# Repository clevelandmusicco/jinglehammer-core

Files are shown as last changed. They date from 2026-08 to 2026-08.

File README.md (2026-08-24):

# Jinglehammer Core - Programmable MIDI Controller

The Jinglehammer Core is a 4 footswitch x 8 bank MIDI controller initially
designed for use with guitar effect pedals, but it can be used to control
anything that understands MIDI messages. Press a footswitch and it sends a
configurable bundle of Program Change and Control Change messages, with each
message free to target its own channel. Configuration lives in onboard flash
and survives power cycles; you edit it from a browser over USB, so there's no
separate app to install.

This repo holds the whole project: `software/` (RP2350 firmware plus the
browser-based config editor), `hardware/` (enclosure CAD and PCB design), and
`docs/` (design notes not tied to a single build artifact).

- Firmware is C + CMake with a VSCode workspace file provided
- Configuration webapp is simple HTML + Javascript with Python used for
  "building"
- PCB sources are in KiCad format and the Gerbers are tested at JLCPCB
- The enclosure source is provided in FreeCAD format, with STEP and 3MF files
  for use in your slicer of choice
  
> [!NOTE]
> Pictures of the hardware and the webapp coming soon.

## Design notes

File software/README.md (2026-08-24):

# Jinglehammer Core

A four-switch MIDI foot controller built on a Raspberry Pi Pico 2 (RP2350). Each
footswitch sends a configurable bundle of Program Change and Control Change
messages over hardware MIDI (UART) and USB-MIDI. Presets, banks, and channels
live in flash and are edited from a browser over USB-CDC. No drivers, no install.

Two pieces, each with its own README:

- [`firmware/`](firmware/README.md) - the C firmware and its Pico SDK build.
- [`webapp/`](webapp/README.md) - a single-file config editor that talks to the
  controller over WebSerial.

This directory is the whole software side. One level up, the repo also holds
`docs/` and `hardware/`, the latter for a 3D-printed enclosure and PCB design
files. Neither is part of any build here.

## Overall UX

The whole controller can effectively be taught in three sentences:

- Press 1–4 to select a preset in the active bank.
- Press the two left- or right-most switches simultaneously to move down or up a bank.
- Solid LEDs indicate Banks 1–4; blinking LEDs indicate Banks 5–8.

**Presets.** Also called "bundles". Selecting a preset sends that switch's message
bundle: Program Changes first, then Control Changes, each message on its own MIDI
channel.

Switches are momentary presets in "radio" mode. The switch you press becomes the
active one, its LED lights, the other three go dark.

**Banks.** Press SW1+SW2 together to step the active bank down, SW3+SW4 to step
it up. Two switches together is a "chord". A chord suppresses both switches'
presets, so changing bank spews no stray MIDI. After a step the LEDs show the
new bank for a little less than a second: banks 1-4 light LED 1-4 solid, banks
5-8 light the same four, but blinking.

Here's a visual of the LED feedback when navigating the banks:

```text
Bank 1 = ● ○ ○ ○
Bank 2 = ○ ● ○ ○
Bank 3 = ○ ○ ● ○
Bank 4 = ○ ○ ○ ●

Bank 5 = ◉ ○ ○ ○
Bank 6 = ○ ◉ ○ ○
Bank 7 = ○ ○ ◉ ○
Bank 8 = ○ ○ ○ ◉
```

where ◉ means blinking.

After one of the above is displayed, all four LEDs slowly pulse for about 2s while the
controller waits for you to pick a preset on the new bank. Pick one and it fires
normally. Pick nothing and the bank navigation is abandoned; the controller returns
to where you started.

Bank changes are RAM-only. Nothing reaches flash until you Save from the web
app, so the bank the controller boots into is whichever one was last written.

## Hardware summary

Four momentary footswitches (normally open to GND, internal pull-ups), four
active-high PWM-driven LEDs, and UART0 TX at 31250 baud into a standard
UART-to-MIDI output stage. MIDI is output only. USB is native and enumerates as
a composite CDC + USB-MIDI device, so the same cable carries MIDI and the config
link.

Pins and counts are in [`firmware/board.h`](firmware/board.h). Full table in the
[firmware README](firmware/README.md).

## Getting started

```sh
git clone https://github.com/clevelandmusicco/jinglehammer-core
cd jinglehammer-core/software
cmake --build firmware/build     # after a one-time configure, see firmware/README.md
./webapp/build.py                # generates webapp/index.html
```

In VSCode, open `jinglehammer.code-workspace` rather than the `software/` folder.
It is a multi-root workspace over `software/`, `firmware/` and `webapp/`, and it
is what makes VSCode pick up each half's `.vscode/` directory: opening `software/`
as a plain folder means `firmware/.vscode/` is never read, so the Pico extension
config, IntelliSense and all the tasks are silently ignored.

Tasks are namespaced by half and independent of each other:

| task | does |
| --- | --- |
| `firmware: build` | incremental `cmake --build build` |
| `firmware: configure` | fresh CMake configure with the SDK and toolchain paths |
| `firmware: clean rebuild` | wipe `build/`, reconfigure, build |
| `firmware: size` | flash/RAM footprint of the ELF |
| `firmware: deploy` | build, then `picotool load -fx` over USB |
| `webapp: build` | inline `src/` into `index.html` |
| `webapp: check` | fail if `index.html` is stale |
| `webapp: test` | rebuild, then run the gjs self-test |
| `webapp: open` | rebuild and open `index.html` in a browser |
| `all: build` | both halves, in parallel |
| `all: verify` | firmware build plus webapp self-test |
| `all: deploy` | firmware build, load over USB, rebuild the editor |

`firmware: deploy` uses picotool's `-f`, which reboots a running board into
BOOTSEL on its own, so you do not need to hold the button. That relies on the
reset interface the firmware exposes (`firmware/usb_reset_iface.c`), so a board
running some older build has to be flashed the manual way once before the task
starts working. The Pico extension's own generated tasks (`Compile Project`,
`Flash`, the reset ones) are still there and still work.

## Work in progress

This is NOT a finished project. Expect a lot of change (improvements?) in the coming
weeks.

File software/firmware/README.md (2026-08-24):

# Jinglehammer Core Firmware

C firmware for the RP2350 (Pico 2). Targets Pico SDK 2.2.0 and board `pico2`.
For what the controller actually does, see the [software README](../README.md); for
the config editor, [`../webapp/`](../webapp/README.md).

## Hardware

Pins, counts, and the MIDI baud rate all live in [`board.h`](board.h).

| Function | GPIO | Notes |
| --- | --- | --- |
| Footswitch 1-4 | GP2, GP3, GP4, GP5 | Momentary, normally open to GND. Internal pull-ups, so a press reads 0. |
| LED 1-4 | GP6, GP7, GP8, GP9 | Active high, PWM-driven so brightness can be faded. LED N pairs with switch N. |
| MIDI out | GP0 (UART0 TX) | 31250 baud 8N1, into a standard UART-to-MIDI output stage (5-pin DIN or TRS-A). Output only. |

> [!WARNING]
> These pins currently don't match the PCB layout! That will be resolved very soon.

USB is native and enumerates as a composite CDC + USB-MIDI device, so the same
cable carries MIDI and the config link.

## Source layout

One responsibility per module:

| File | Responsibility |
| --- | --- |
| `board.h` | Pins, counts, MIDI UART baud. |
| `config.[ch]` | Persisted data model, CRC-32, flash load/save, serialize seams. |
| `midi.[ch]` | Builds PC/CC bytes, emits a preset bundle to UART + USB. |
| `io.[ch]` | Polled switch debounce and PWM LED output. |
| `controller.[ch]` | Radio policy and bank navigation: press edges to MIDI + LEDs. |
| `cdc_proto.[ch]` | Framed read/write/save command set on USB-CDC. Non-blocking. |
| `main.c` | Init plus the super-loop. |
| `usb_descriptors.c`, `tusb_config.h` | TinyUSB composite CDC + MIDI device. |

Dependency direction: `main` wires everything; `controller` uses `config`,
`midi`, `io`; `cdc_proto` uses `config`; `midi` and `config` use `board`; `io`
uses `board`. No cycles.

## Setting up the Pico toolchain

For a fresh Pico 2 with nothing installed yet, use VS Code — it sets up
everything in one step and needs no manual PATH wrangling.

1. Install [VS Code](https://code.visualstudio.com/) and the
   [Raspberry Pi Pico extension](https://marketplace.visualstudio.com/items?itemName=raspberry-pi.raspberry-pi-pico).
2. Open [`software/jinglehammer.code-workspace`](../jinglehammer.code-workspace)
   in VS Code (not a plain folder). It's a multi-root workspace with this
   folder as one of the roots, which is what the checked-in
   [`.vscode/`](.vscode) config and the extension's path resolution need — VS
   Code only reads a folder's `.vscode/` when that folder is itself a
   workspace-folder root. Opening `software/` or the repo root as a plain
   folder skips it, and the Build/Flash buttons end up pointed at a build
   directory that doesn't exist.
3. Run the extension's "Import Project" flow once (it detects the existing
   `CMakeLists.txt`). This downloads the SDK, ARM toolchain, CMake, Ninja,
   OpenOCD, and picotool into `~/.pico-sdk/` — nothing is installed system-wide.

That's it. The extension's Configure / Build / Flash buttons work from here on.

**Manual setup** (skip the extension, use the CLI below): put the same tools
under `~/.pico-sdk/` yourself — Pico SDK 2.2.0 at `~/.pico-sdk/sdk/2.2.0`, ARM
toolchain 14_2_Rel1 at `~/.pico-sdk/toolchain/14_2_Rel1`, plus CMake, Ninja, and
picotool (any recent version of these three is fine).

## Building and flashing

### First flash, out of the box

A brand new Pico 2 has no firmware with the custom reset interface, so its
*only* way in is BOOTSEL mode:

1. Hold the **BOOTSEL** button, plug in USB, then let go. The board mounts as
   a mass-storage drive named `RP2350`.
2. Build the firmware (from this directory):

   ```sh
   cmake -S . -B build -G Ninja \
     -DPICO_SDK_PATH=$HOME/.pico-sdk/sdk/2.2.0 \
     -DPICO_TOOLCHAIN_PATH=$HOME/.pico-sdk/toolchain/14_2_Rel1 \
     -DPICO_BOARD=pico2
   cmake --build build
   ```

   Output: `build/midi_ctrl.uf2`.
3. Copy `build/midi_ctrl.uf2` onto the `RP2350` drive. The board flashes
   itself and reboots into the new firmware.

It now comes up on factory defaults: bank 1, four presets, switch 1 sending a
PC on channel 1 plus three CCs on channels 2 and 3.

### Every flash after that

Once the board is running a build that includes `usb_reset_iface.c` (true
after the first flash above), you don't need BOOTSEL again — the board can
reset itself over the USB cable:

```sh
cmake --build build
picotool load -fx build/midi_ctrl.uf2
```

`-f` reboots the board into BOOTSEL and `-x` runs the new image immediately
after.

**SWD** (CMSIS-DAP probe, VS Code task `Flash`) works too, for when USB isn't
an option. But most folks find `picotool load -fx` to be simpler.

## Debugging

stdio is off on both USB and UART0 by default: USB belongs to TinyUSB (CDC +
MIDI) and UART0 is the MIDI port. To get `printf` out, route stdio to a spare
UART, add `pico_enable_stdio_uart(midi_ctrl 1)` to `CMakeLists.txt`, and call
`stdio_init_all()` in `main`.

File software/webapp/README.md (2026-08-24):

# Config editor

`index.html` is the editor for the controller's presets, banks, and channels.
It talks over USB-CDC using WebSerial, so it opens straight off disk with
nothing installed. See the [software README](../README.md) for the
controller itself and [`../firmware/`](../firmware/README.md) for the device
side.

## Building

`index.html` is generated from `src/` and is not checked in, so build it once
after cloning:

```sh
./build.py
```

That inlines the template, CSS, and JS modules into one self-contained file.
No npm and no bundler; it is plain Python 3 stdlib, so it runs the same on
Linux, macOS, and Windows. The app has to ship as a single file because
WebSerial works from `file://` but ES modules do not.

- `./build.py --check` exits 1 if `index.html` is stale.
- `./test.py` rebuilds, then self-tests the byte codec and page load. Needs
  `gjs` (Debian/Ubuntu: `apt install gjs`).

Both scripts resolve their own directory from the script path, so they run
from any working directory.

Edit `src/`. Anything written to `index.html` is lost on the next build.

## Source layout

```text
src/index.template.html   page skeleton plus <!-- include: ... --> lines
src/style.css
src/js/config-schema.js   field table mirroring config_t, plus decode/encode
src/js/crc32.js           CRC-32 matching the firmware's
src/js/model.js           in-RAM blob and edit folding
src/js/protocol.js        CDC frame codec
src/js/commands.js        HELLO / READ / WRITE / SAVE / FACTORY / TEST
src/js/monitor.js         raw-frame monitor, taps Link.send and Link._parse
src/js/paging.js          bank tabs, edit vs active bank
src/js/render.js          DOM building
src/js/status.js          status pill and banner
src/js/wiring.js          button listeners and startup
test/selftest.js          codec offsets and page-load test, run by test.py
```

`config-schema.js` mirrors the firmware's `config_t` name-for-name, and every
offset in the app derives from that one table. The constants in
`test/selftest.js` are hand-computed on purpose, so the schema cannot silently
agree with itself. A format change means editing both, plus `CONFIG_VER`.

## Editing presets

Open `index.html` in a Chromium-based browser (Chrome or Edge; Firefox and
Safari do not ship WebSerial). Plug the controller in over USB, then:

1. **Connect**, and pick the controller from the browser's port chooser.
2. **Read** to pull the current config off the device.
3. Edit each preset: name, plus its Program Change and Control Change
   lists (up to 16 of each, every message with its own 1-16 MIDI channel).
   **Test** plays a switch's bundle immediately from the on-screen values,
   without saving. Numbered tabs page through the 8 banks, and **Set as
   active** marks the bank the controller runs and boots on.
4. **Write + Save** sends all 8 banks and commits them to flash.

**Factory reset** overwrites the saved config with the built-in defaults.
**Frames** opens a raw-frame monitor for debugging the CDC link.

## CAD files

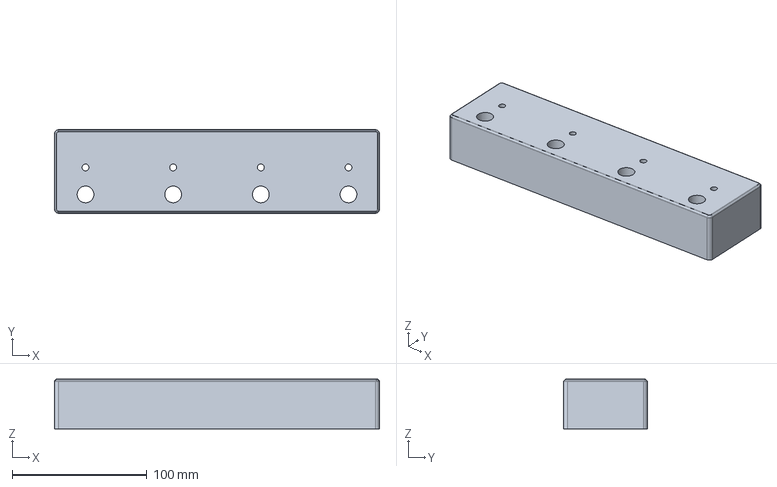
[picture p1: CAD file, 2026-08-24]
hardware/enclosure/enclosure-core.FCStd
241.0 x 62.0 x 37.0 mm

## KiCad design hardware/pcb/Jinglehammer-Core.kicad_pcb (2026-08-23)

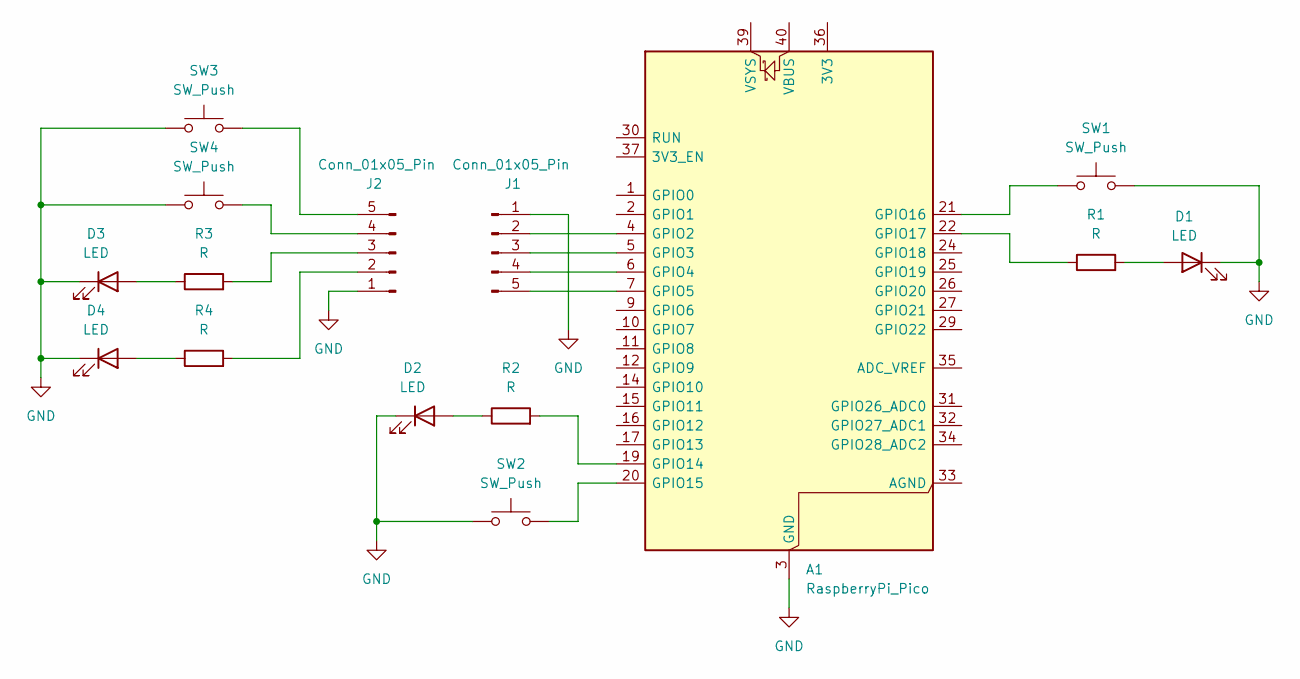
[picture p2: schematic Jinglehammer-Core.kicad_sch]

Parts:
A1: RaspberryPi_Pico; RaspberryPi_Pico_Common_Unspecified
D1, D2, D3, D4: LED; LED_D5.0mm
J1, J2: Conn_01x05_Pin; PinHeader_1x05_P2.54mm_Vertical
R1, R2, R3, R4: R; R_Axial_DIN0207_L6.3mm_D2.5mm_P7.62mm_Horizontal
SW1, SW2, SW3, SW4: SW_Push; Switch_Footswitch_PBS-24B-2_DirectMount

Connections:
GND: A1.3 (GND), A1.8 (GND), A1.13 (GND), A1.18 (GND), A1.23 (GND), A1.28 (GND), A1.38 (GND), D1.1 (K), D2.1 (K), D3.1 (K), D4.1 (K), J1.1, J2.1, SW1.1, SW2.1, SW3.1, SW4.1
unnamed: A1.4 (GPIO2), J1.2
unnamed: A1.5 (GPIO3), J1.3
unnamed: A1.6 (GPIO4), J1.4
unnamed: A1.7 (GPIO5), J1.5
unnamed: A1.19 (GPIO14), R2.2
unnamed: A1.20 (GPIO15), SW2.2
unnamed: A1.21 (GPIO16), SW1.2
unnamed: A1.22 (GPIO17), R1.1
unnamed: D1.2 (A), R1.2
unnamed: D2.2 (A), R2.1
unnamed: D3.2 (A), R3.1
unnamed: D4.2 (A), R4.1
unnamed: J2.2, R4.2
unnamed: J2.3, R3.2
unnamed: J2.4, SW4.2
unnamed: J2.5, SW3.2

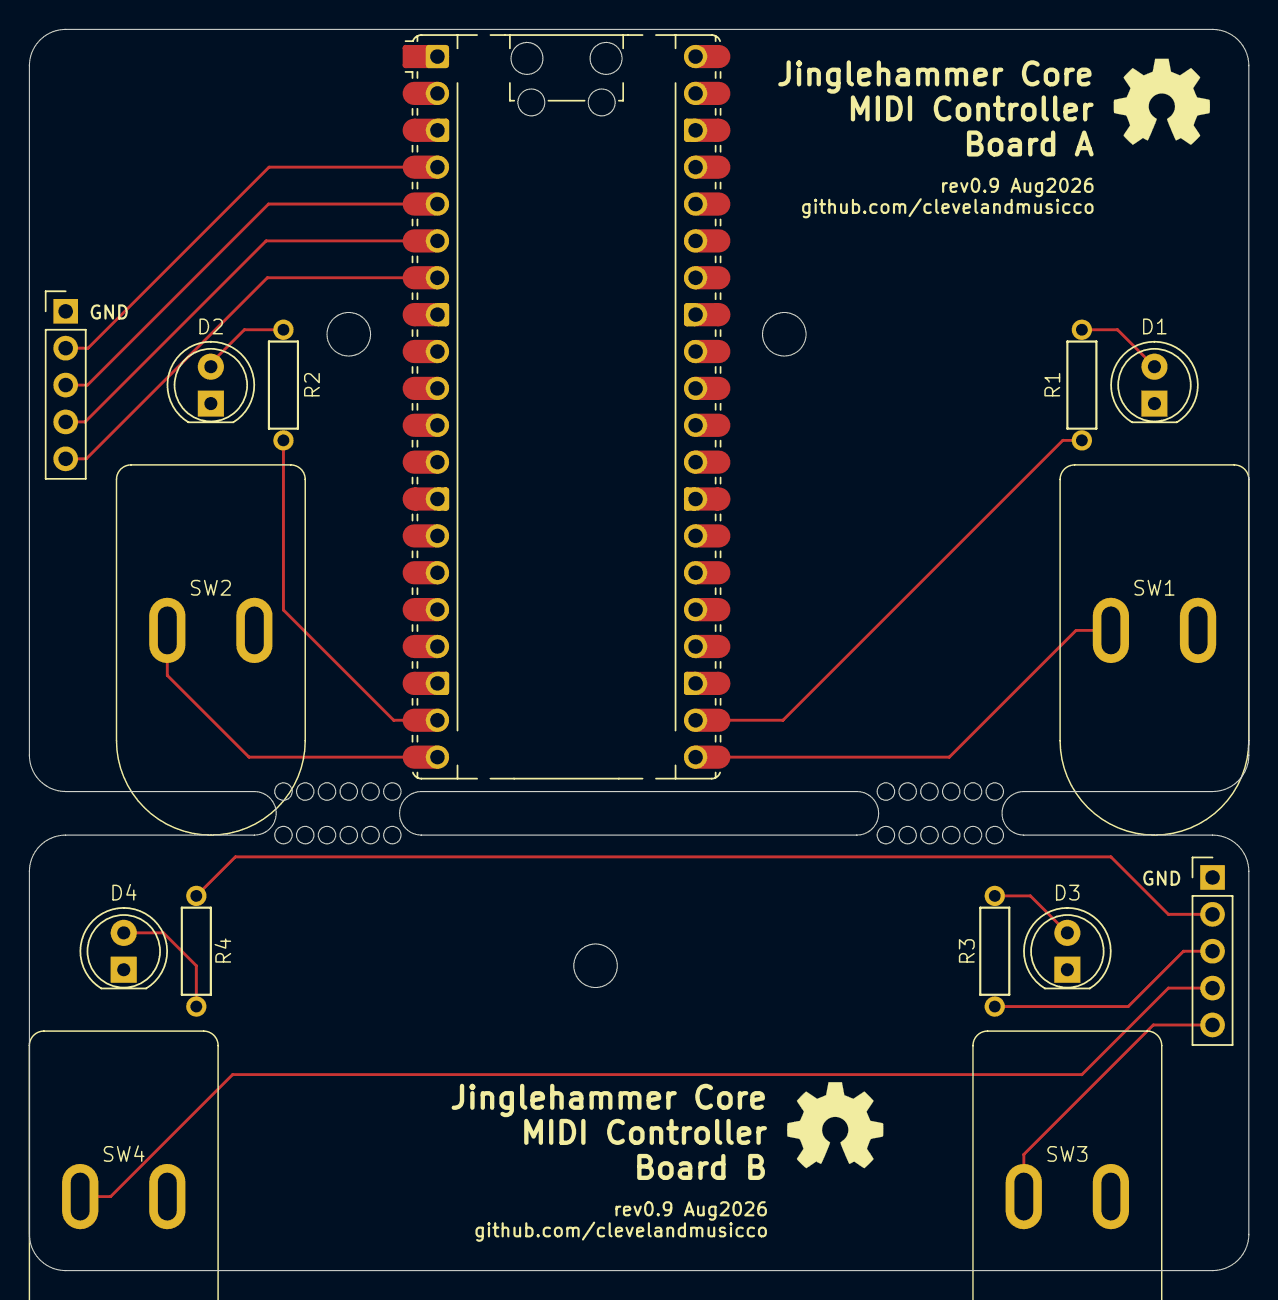
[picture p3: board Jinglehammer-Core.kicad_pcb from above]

Board: 2 copper layers, 84.0 x 85.5 mm, 15 parts (0 on the bottom side), 17 nets.

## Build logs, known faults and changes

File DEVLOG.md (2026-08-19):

# DEVLOG: bank-nav branch

Working log for the bank-navigation feature, branched off `main`. Purpose: let
future sessions (or future me) resume without re-deriving decisions already
made. Update this file each commit; keep it current, not historical - prune
resolved "open questions" rather than leaving them stale.

## Goal

Add bank up/down navigation on the footswitches, plus a temporary LED readout
of which bank is now active. Scope for this branch is mechanics + indicator
only; no webapp changes, no new switch modes beyond what's needed for this.

First cut used double-tap on SW1/SW4. Superseded (see below) by a two-switch
chord: double-tap fired each tap's own preset in addition to stepping the
bank, so a bank change always came with an unwanted MIDI fire from whichever
preset lived on that switch.

## Status

- `21667e1` - double-tap detection + bank step (`controller.c`) - **superseded**
- `4c79de1` - LED bank-display on top of that (`controller.c`, `controller.h`, `main.c`) - display logic carried forward as-is
- `71eb2a9` - replaced double-tap with a chord gesture; see Behaviour below.
- Current (uncommitted) - preset-wait after bank-display timeout, replacing
  the old "LED 0 = preset 1" placeholder; see Preset-wait section below.
- Not yet done: flashed/tested on real hardware. Everything below is
  desk-reviewed and builds clean, not yet felt with a boot.

## Behaviour, as built

- SW1+SW2 pressed together -> `active_bank -= 1`; SW3+SW4 together ->
  `active_bank += 1`. Clamped at 0 / `NUM_BANKS-1` (no wrap).
- A recognised chord suppresses both switches' normal preset fire entirely -
  only the bank step and LED display happen. This is the whole point of the
  switch from double-tap: no more MIDI collision between "I meant to change
  bank" and "that switch also has a preset."
- Chord partner pairing is `i ^ 1`: switches (0,1) are the down pair, (2,3)
  the up pair.
- Detection uses a tolerance window, not exact same-tick simultaneity. Each
  switch debounces independently (8ms shift register, see `io.c`), all four
  sampled in the same `io_poll()` call - but two real footswitch presses
  aimed at "the same moment" can still complete a poll tick or two apart. So
  every edge on SW1-4 is held pending for `CHORD_WINDOW_MS` (20ms: 8ms
  debounce + slack for press skew): if the partner edge shows up before the
  deadline (same tick or a later one), it's a chord - bank step fires,
  neither preset does, and the first-arriving switch's pending entry is
  cancelled without ever firing. If the deadline passes with no partner, it
  was a solo press - the queued preset fires then, late by at most
  `CHORD_WINDOW_MS`.
  - Consequence: **every** press on SW1-4 now carries up to 20ms of added
    latency, even a plain single-switch press, since the firmware can't know
    in advance whether a chord partner is coming. This is a deliberate
    tradeoff (user's call, see chat history) - 20ms is inaudible/imperceptible
    for PC/CC messages, traded for chords being reliably hittable by foot
    instead of requiring exact-tick luck.
- `active_bank` change is RAM-only - no `config_save()` call. Cheap to spam,
  survives until a webapp Save or reverts to the last-Saved bank on reboot.
- On a recognised chord (even one that clamps to the same bank - that's the
  "you're already at the end" feedback), LEDs switch to bank-display mode for
  800ms: LED `(bank % NUM_SWITCHES)` lights, solid for banks 1-4, blinking for
  banks 5-8. Unchanged from the double-tap version.
- Blink = 4 on/off cycles at 100ms/state, fills the 800ms window exactly.
- A later chord while the display is showing restarts the window/blink
  against the new bank.
- Any normal switch press (chord or solo-fire-after-timeout) preempts the
  display immediately and shows that press's radio LED instead - a fired
  preset always wins over a stale bank indicator.
- On bank-display timeout, the unit does **not** default to preset 1 - see
  "preset-wait" below, added after this was flagged as misleading (stepping a
  bank shouldn't silently imply picking a preset on it).

## Preset-wait (uncommitted, on top of the above)

Resolves the open question below about what happens after the bank-display
window: previously LED 0 lit as a "preset 1 of the new bank" placeholder with
no MIDI sent, which read as if a preset had actually been selected. Now:

- When `BANK_DISPLAY_WINDOW_MS` elapses, the unit enters a new LED mode
  (`LED_MODE_AWAIT_PRESET`) instead of returning straight to radio mode: all 4
  LEDs breathe together for `PRESET_WAIT_WINDOW_MS` (2000ms) - fade low-\>high
  over `PRESET_WAIT_STATE_MS` (500ms), then high-\>low over the next 500ms,
  repeat - 2 up/down cycles fill the window exactly, same "N units fill the
  window" pattern as the bank blink, just continuous brightness instead of a
  hard on/off toggle.
- First cut used a hard on/off blink (250ms/state, 4 cycles), same mechanism
  as bank-display's blink. Replaced with an actual fade after the ask for a
  smoother "breathing" look instead of a blink - see the `io.c` change below.
- Any normal press during the fade (chord or solo) preempts it immediately,
  same rule as bank-display preemption - the newly fired preset's radio LED
  wins and becomes the active preset going forward.
- Another chord during the fade restarts bank-display again against the
  further-stepped bank, then re-enters preset-wait - chaining chords keeps
  extending the sequence rather than committing anything.
- If the 2000ms window lapses with nothing picked, the whole navigation
  sequence is abandoned: `active_bank` reverts (RAM-only) to whatever it was
  *before the first chord in the sequence*. This is the literal "keep the old
  bank and preset" ask - a bank step is now provisional until a preset
  confirms it.
- First cut of the revert set the reverted-to preset's LED directly, with no
  indication a revert had even happened - visually indistinguishable from
  just picking that preset normally. Fixed per feedback: the revert now lands
  `active_bank` in RAM, then calls `start_bank_display(true)` to replay the
  *normal* bank-display readout (same position/blink code) for the bank
  being reverted to, and only after that window ends does it settle on the
  LED of the preset that was actually active before all this started (or off,
  pre-first-press). Worked example: bank 5 preset 3 active, SW3+4 steps to
  bank 6, nothing picked in time -> LED1 blinks (bank 5's display code),
  then LED3 lights solid (preset 3) - reads as "back to bank 5, preset 3,"
  not a silent snap.
- `start_bank_display()` takes an `is_revert` bool, stashed in
  `bank_display_revert`, so `controller_poll()` knows what to do once that
  display's own window ends: forward nav (`is_revert == false`) chains into
  `start_preset_wait()` as before; a revert (`is_revert == true`) settles
  straight into `LED_MODE_RADIO` showing `active_switch`. Same struct/timer/
  blink fields serve both cases - it's the same display, just two different
  reasons to be showing it and two different next steps.
- `controller_on_edges()` snapshots `g_config.active_bank` before its
  `bank_step()` call, but only commits it to `pre_nav_bank` (the revert
  target) when the sequence starts from `LED_MODE_RADIO` - a chord that lands
  mid-display or mid-wait (including during a revert's own display) must not
  overwrite the revert target with an intermediate bank. A fresh chord
  landing during a revert's display works out correctly anyway: by then
  `active_bank` has already been set to `pre_nav_bank` in RAM, so stepping
  from "current" and stepping from "the bank being reverted to" are the same
  number - the new chord just starts a normal forward nav from there,
  `bank_display_revert` gets reset to `false` for it, and `pre_nav_bank`
  isn't touched because `led_mode` isn't `LED_MODE_RADIO` at that instant.
- `controller_poll()` now does three jobs: fires any preset whose chord window
  expired with no partner, drives the bank-display deadline/blink, and drives
  the preset-wait deadline/fade (including the revert). All need to progress
  with no switch presses arriving, hence still polled every ~1ms from
  `main.c` independent of edges. The fade level is recomputed every poll tick
  (not just at the 500ms state boundary) by linearly interpolating elapsed
  time within the current ramp, so it reads as continuous motion rather than
  256 possible steps landing only every 500ms.
- `io.c` LEDs moved from plain `gpio_put` to hardware PWM
  (`gpio_set_function(..., GPIO_FUNC_PWM)`, 8-bit duty, `hardware_pwm` added
  to `target_link_libraries` in `CMakeLists.txt`) so brightness is controllable
  at all - `io_set_leds(mask)` keeps the old on/off call shape (duty 0 or 255),
  new `io_set_leds_level(level)` sets all 4 LEDs to the same 0-255 duty for the
  fade. LED1/LED2 (GP6/7) and LED3/LED4 (GP8/9) each share a PWM slice, but
  channels A/B have independent compare registers, so per-LED brightness
  still works independently - just don't call `pwm_init()` again after
  `io_init()`, since it resets both channels' compare registers on that slice.

## Known limits / assumptions

- Bank-display encoding (`position = bank % NUM_SWITCHES`, `blink = bank >=
  NUM_SWITCHES`) is only unambiguous up to `2 * NUM_SWITCHES` banks.
  `NUM_BANKS` is exactly that today (8 = 2*4). If `NUM_BANKS` ever grows past
  that, the display silently aliases - no guard exists for it, out of scope
  for this branch.
- Chord pairing (`i ^ 1`, delta by `i < 2`) is hardcoded for exactly 4
  switches split into two fixed pairs. Fine at `NUM_SWITCHES == 4`; would need
  rework if the switch count or pairing ever changes.
- Timing (chord window, display window, blink) is wall-clock (`absolute_time_t`
  / `time_reached`), not tied to poll count, so it degrades gracefully if
  `controller_poll()` call cadence ever drifts from 1ms - just coarser, not
  broken.
- No flash write ever happens from a chord. Same deliberate tradeoff as the
  double-tap version - flash write is blocking + wears the sector, bad fit for
  something tapped often mid-set.

## Open questions / next steps

- Hardware feel: `CHORD_WINDOW_MS` (20ms), 800ms display window, 100ms blink
  cadence - all reasonable guesses, untested on a real footswitch. The chord
  window in particular may need tuning: too short and intentional chords miss
  each other's tick, too long and fast sequential solo presses on SW1-4 risk
  being misread as a chord.
- Webapp is untouched. `active_bank` can now drift from what the webapp last
  saw without a Save - probably fine (Read already re-syncs), but no explicit
  decision was made about surfacing this in the UI.
- Fixed after the fact: nav state outlived the config it referred to. A web-app
  Write + Save (or factory reset) mid-nav got undone by the pending revert
  writing `pre_nav_bank` back over the bank the host had just installed - and a
  revert landing in the gap between WRITE and SAVE put the stale bank in flash.
  `config.c` now bumps `g_config_epoch` on every wholesale replacement,
  `controller_poll()` checks it ahead of its timeout handling and cancels the
  nav, and the same hook replays the bank readout so a Save is acknowledged on
  the unit. Pending presses survive the cancel: they are real presses and fire
  against the new config.
- Non-preset switch modes (latching, hold for something other than bank nav)
  still not started - unrelated to this branch, just noting so it's not
  confused with in-scope work.

## How to resume in a new session

- Read `controller.c`'s top-of-file comment block first - kept in sync with
  behaviour, describes the policy inline. This file is the "why we chose
  this," that one is the "what it does."
- Build: `cmake --build build` (build dir already configured, see root
  `CLAUDE.md`).
- Flash: no BOOTSEL-less USB path exists for this firmware - confirmed
  `picotool load -f` won't work here (raw TinyUSB composite device, no
  `pico_stdio_usb`/vendor reset interface, `CFG_TUD_VENDOR 0`). Use the SWD
  path instead: VS Code task `Flash` (`openocd` + CMSIS-DAP probe), already
  wired up in `.vscode/tasks.json`. Requires a physical debug probe on the
  board's SWD pads.

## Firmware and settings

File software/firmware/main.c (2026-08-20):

#include "pico/stdlib.h"
#include "tusb.h"

#include "board.h"
#include "config.h"
#include "midi.h"
#include "io.h"
#include "controller.h"
#include "cdc_proto.h"

/* Footswitch poll period. Sets the debounce time base (see io.c). */
#define POLL_INTERVAL_MS 1

int main(void)
{
    /* TinyUSB (SDK 2.2.0 API): device role, speed auto-detected. */
    tusb_rhport_init_t dev_init = {
        .role  = TUSB_ROLE_DEVICE,
        .speed = TUSB_SPEED_AUTO,
    };
    tusb_init(BOARD_TUD_RHPORT, &dev_init);

    midi_init();
    io_init();

    /* First boot or a corrupt blob -> write factory defaults so flash is valid. */
    if (!config_load()) {
        config_load_defaults();
        config_save();
    }

    controller_init();

    absolute_time_t next_poll = make_timeout_time_ms(POLL_INTERVAL_MS);

    for (;;) {
        tud_task(); /* keep USB serviced as fast as the loop turns */

        /* CDC config link (non-blocking, never stalls pedals). */
        cdc_proto_task();

        /* Drain inbound USB-MIDI (non-blocking, don't stall pedals). */
        while (tud_midi_available()) {
            uint8_t pkt[4];
            tud_midi_packet_read(pkt);
        }

        if (time_reached(next_poll)) {
            uint8_t edges = io_poll();
            if (edges)
                controller_on_edges(edges);
            controller_poll();

            /* Guard debounce window: if blocking ops (UART/flash writes) stall,
             * re-anchor poll to now+1ms to avoid catch-up collapse. */
            next_poll = delayed_by_ms(next_poll, POLL_INTERVAL_MS);
            if (time_reached(next_poll))
                next_poll = make_timeout_time_ms(POLL_INTERVAL_MS);
        }
    }
}

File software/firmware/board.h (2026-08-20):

#pragma once

#include <stdint.h>

/*
 * Board / front-panel wiring and compile-time limits.
 *
 * Everything hardware-specific lives here so re-pinning the controller is a
 * one-file edit. Footswitch N is logically paired with LED N (1-indexed on
 * the panel, 0-indexed in code).
 */

/* ---- Front panel ---------------------------------------------------------- */

#define NUM_SWITCHES 4u

/*
 * Footswitch GPIOs: momentary, normally-open to GND. We enable the internal
 * pull-up, so a press reads logic-0. Wire each switch between the pin and GND.
 */
#define FSW1_PIN 2u
#define FSW2_PIN 3u
#define FSW3_PIN 4u
#define FSW4_PIN 5u

/* LED GPIOs: active-high (pin high = lit). LED N pairs with FSW N. */
#define LED1_PIN 6u
#define LED2_PIN 7u
#define LED3_PIN 8u
#define LED4_PIN 9u

/* ---- Hardware MIDI out (5-pin DIN / TRS) ---------------------------------- */

/*
 * MIDI is output-only here. Drive MIDI_TX_PIN into a standard UART->MIDI
 * output stage (current-loop with a 5-pin DIN, or a TRS-A jack). 31250 baud,
 * 8N1, is the MIDI 1.0 wire rate.
 */
#define MIDI_UART    uart0
#define MIDI_TX_PIN  0u /* GP0 = UART0 TX */
#define MIDI_BAUD    31250u

/* ---- Config data-model limits (compile-time) ------------------------------ */

/* Max PC and CC messages a single switch press can emit. */
#define MAX_PC_PER_SWITCH 16u
#define MAX_CC_PER_SWITCH 16u

/*
 * Preset name buffer, bytes including the mandatory trailing NUL: up to 15
 * visible chars. Sized to one line of a 16-col LCD / SSD1306 OLED, which is
 * where this label is headed. Stored per preset in the flash blob.
 */
#define MAX_NAME_LEN 16u

/*
 * Banks held by the data model. All of them sit in the flash blob; which one is
 * live is config.active_bank, stepped by footswitch chord (controller.c) or set
 * by the web app. Raising this past 2*NUM_SWITCHES makes controller.c's LED
 * bank readout ambiguous - it encodes a bank as LED position plus blink/solid,
 * and that runs out at 8.
 */
#define NUM_BANKS 8u

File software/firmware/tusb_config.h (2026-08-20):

#pragma once

#ifndef BOARD_TUD_RHPORT
#define BOARD_TUD_RHPORT    0
#endif

#ifndef BOARD_TUD_MAX_SPEED
#define BOARD_TUD_MAX_SPEED OPT_MODE_DEFAULT_SPEED
#endif

#ifndef CFG_TUSB_MCU
#error CFG_TUSB_MCU must be defined
#endif

#ifndef CFG_TUSB_OS
#define CFG_TUSB_OS         OPT_OS_NONE
#endif

#define CFG_TUD_ENABLED     1
#define CFG_TUD_MAX_SPEED   BOARD_TUD_MAX_SPEED

#ifndef CFG_TUSB_MEM_SECTION
#define CFG_TUSB_MEM_SECTION
#endif

#ifndef CFG_TUSB_MEM_ALIGN
#define CFG_TUSB_MEM_ALIGN  __attribute__ ((aligned(4)))
#endif

#ifndef CFG_TUD_ENDPOINT0_SIZE
#define CFG_TUD_ENDPOINT0_SIZE  64
#endif

#define CFG_TUD_CDC             1
#define CFG_TUD_MSC             0
#define CFG_TUD_HID             0
#define CFG_TUD_MIDI            1
#define CFG_TUD_VENDOR          0

/* Buffer frames without per-byte FIFO stalls (config ~1.7 KB). */
#define CFG_TUD_CDC_RX_BUFSIZE  256
#define CFG_TUD_CDC_TX_BUFSIZE  256

#define CFG_TUD_MIDI_RX_BUFSIZE (TUD_OPT_HIGH_SPEED ? 512 : 64)
#define CFG_TUD_MIDI_TX_BUFSIZE (TUD_OPT_HIGH_SPEED ? 512 : 64)

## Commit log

2026-08-19 Add chord-based bank navigation with LED bank display
    SW1+SW2 steps active_bank down, SW3+SW4 up (clamped, RAM-only).
    Detection holds each edge pending briefly to catch a partner edge
    landing a poll tick later, since switches debounce independently -
    adds small constant latency to every solo press on SW1-4. A chord
    suppresses both switches' preset fire entirely.
    LEDs repurpose after a bank step: bank-position/blink readout, then
    breathing fade (LEDs moved to hardware PWM) while waiting for a
    preset pick on the new bank. No pick before the window lapses
    reverts active_bank and replays the readout for it, so a revert
    reads as "back to bank X, preset Y" instead of a silent snap.
    Also: README,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
    [io.c, main.c]
2026-08-20 Reorganize repo and add USB self-reset reflash
    Git root moves up out of the old firmware directory: firmware sources and
    their CMake tree to software/firmware/, config editor to software/webapp/,
    design notes to docs/, empty hardware/ placeholder. .gitignore moves to the
    root with its paths fixed and the README splits three ways.
    Adds software/jinglehammer.code-workspace, a multi-root workspace over
    software/, firmware/ and webapp/, plus "firmware: *", "webapp: *" and
    "all: *" tasks. Without the workspace VSCode never reads firmware/.vscode/,
    so the Pico extension config, IntelliSense and every task go unread.
    Adds picotool's vendor reset interface (class 0xff, no endpoints) via
    TinyUSB's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
    [board.h, io.c]
2026-08-20 Trim firmware comments; serialize webapp CDC commands
    Firmware: shrink verbose block comments to terse one-liners, no
    logic change.
    Webapp: Link.send used one pending slot, so an overlapping command
    (e.g. Test fired mid-Save) could steal another's response. Queue
    sends instead of trusting callers to serialize.
2026-08-23 Add hardware source files
    These are starting points and will definitely change. FreeCAD and KiCad both
    generate a boatload of temp files, so we'll tweak the .gitignore as we go.
    [Jinglehammer-Core.kicad_pcb, Jinglehammer-Core.kicad_sch, enclosure-core.FCStd]
2026-08-24 Add PCB standoff support to enclosure
    Still TODO: cut USB connector hole into side of the enclosure; these standoffs will stabilise the PCB for more precise measurement
    [enclosure-core.FCStd]
